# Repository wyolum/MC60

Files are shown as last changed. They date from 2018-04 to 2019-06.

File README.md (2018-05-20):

# MC60
break out board for Quectel MC60 Ultra-small LCC Quad-band GSM/GPRS/GNSS Module

http://www.quectel.com/product/mc60.htm

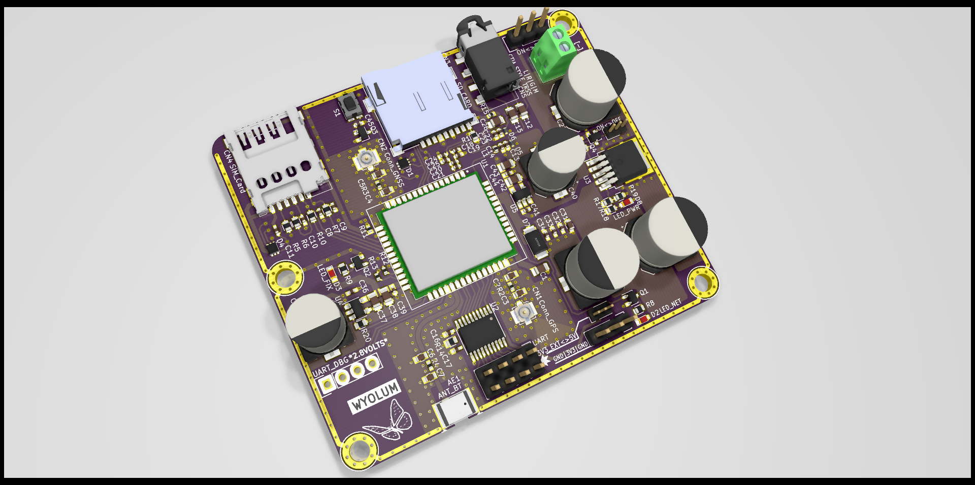
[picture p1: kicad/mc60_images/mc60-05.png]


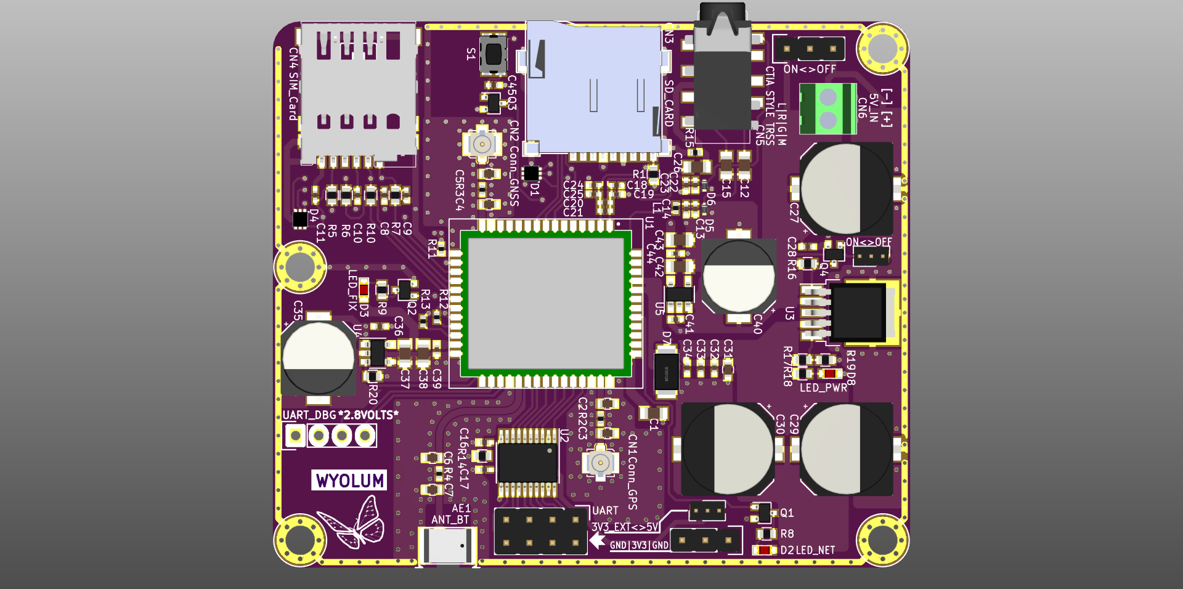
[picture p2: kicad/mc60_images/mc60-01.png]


License
-------
[CERN Open Hardware Licence v1.2 ]

[CERN Open Hardware Licence v1.2 ]:http://www.ohwr.org/attachments/2388/cern_ohl_v_1_2.txt

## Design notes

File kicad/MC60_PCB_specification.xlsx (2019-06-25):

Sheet: Template
PCB Name 名称 | MC60
Board Size 尺寸 | Length*width (Unit:mm) | 70 | * | 60
Material 板材 | (Rigid) FR－4 | Special Requirement:
Layers 层数 | 2 | Special Requirement:
Thickness 厚度 | 1.6 mm | Special Requirement:
Copper Weight 铜厚 | 1 oz. | Special Requirement:
Soldermask Color 阻焊颜色 | White | Special Requirement:
Silkscreen Color 丝印颜色 | Black | Special Requirement:
Surface Finishing 焊盘喷镀 | HASL Lead Free | Special Requirement:
Via soldermask 阻焊覆盖 | Soldermask Cover | Special Requirement:
Mini trace/spacing 最小线宽 | 0.20 mm | Special Requirement:
Mini hole size 最小孔径 | 0.40 mm | Special Requirement:
Special requirements 特殊工艺
 | Other Special requirements：

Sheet: Parameter
PCB Material | Layers | Thickness | Copper Weight | Soldermask Color | Silkscreen Color | Surface Finishing | Via soldermask | Mini trace/spacing | Mini hole size
FR-4 | 1 Layer | 0.6mm | 0.5 oz | Green | White | HASL Lead Free(RoHS) | Soldermask Cover | 4 mil or 0.10 mm | 6 mil or 0.15 mm
Flexible Printed Circuit | 2 Layer | 0.8mm | 1 oz | Red | Black | ENIG | Soldermask Opening | 5 mil or0.13 mm | 8 mil or 0.2 mm
Rogers 4003 | 4 Layer | 1.0mm | 2 oz | Blue | Yellow | OSP |  | 6 mil or 0.15 mm | 10 mil or 0.25 mm
Rogers 4350 | 6 Layer | 1.2mm | 3 oz | Black | Red | Immersion Tin |  | 8 mil or 0.20 mm | 12 mil or 0.30 mm
Taconic Series | 8 Layer | 1.3mm | Other | White | Other | Immersion Sliver
Aluminum-based material | 10 Layer | 1.6mm |  | Green Matte |  | Hard Gold
RF-35 | 12 Layer | 2.0mm |  | Blue Matte |  | Other
Arlon | 14 Layer | 2.5mm |  | Black Matte
Other | 16 Layer | 3.0mm |  | Other
 | Other | Other

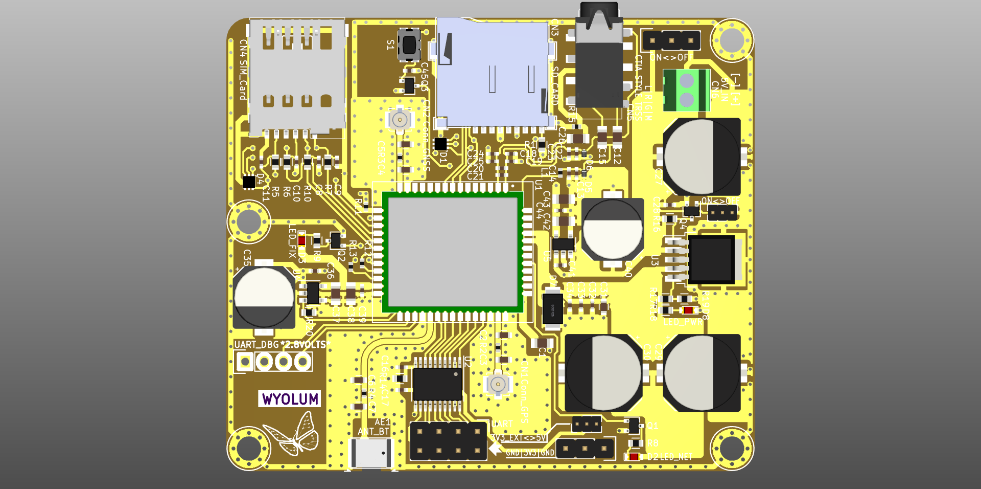
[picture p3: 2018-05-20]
kicad/mc60_images/mc60-03.png

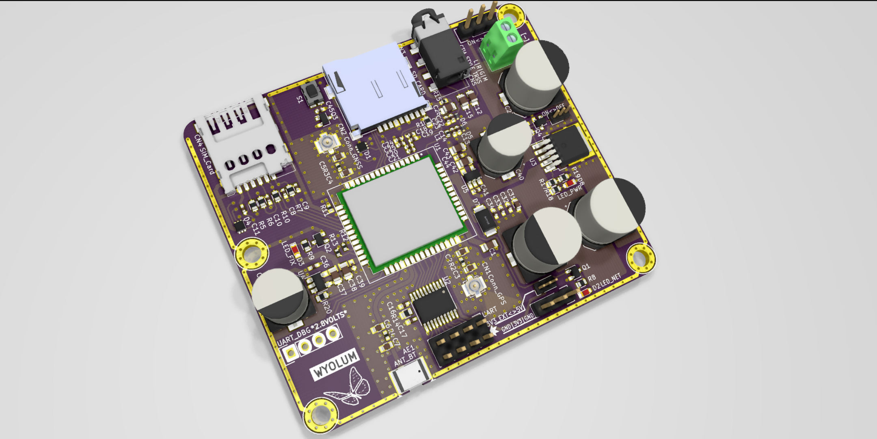
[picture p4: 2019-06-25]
kicad/mc60_images/mc60-05_2160x1080.png

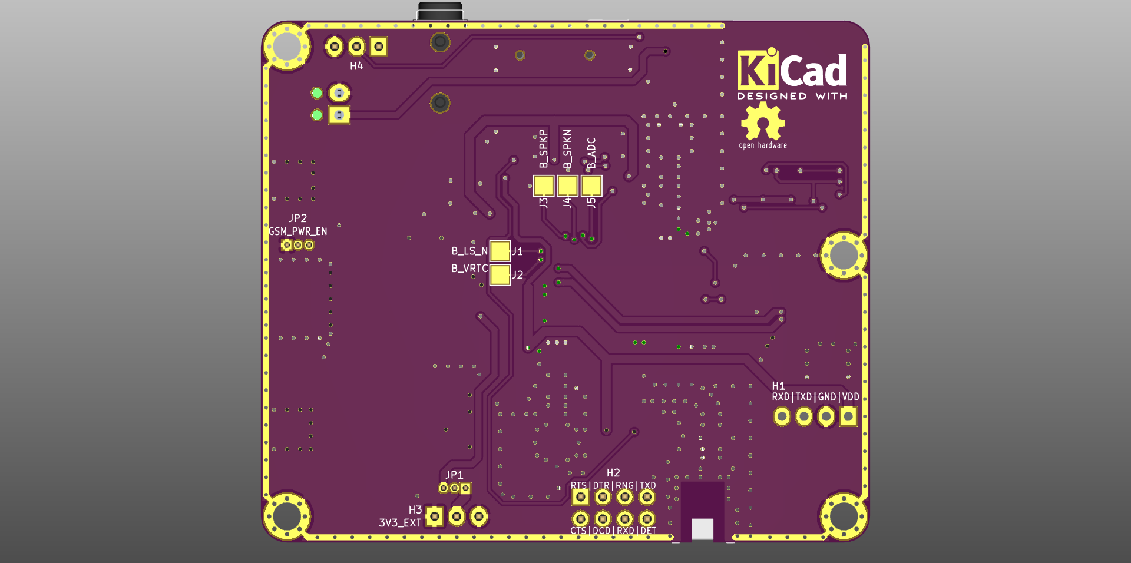
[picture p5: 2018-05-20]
kicad/mc60_images/mc60-02.png

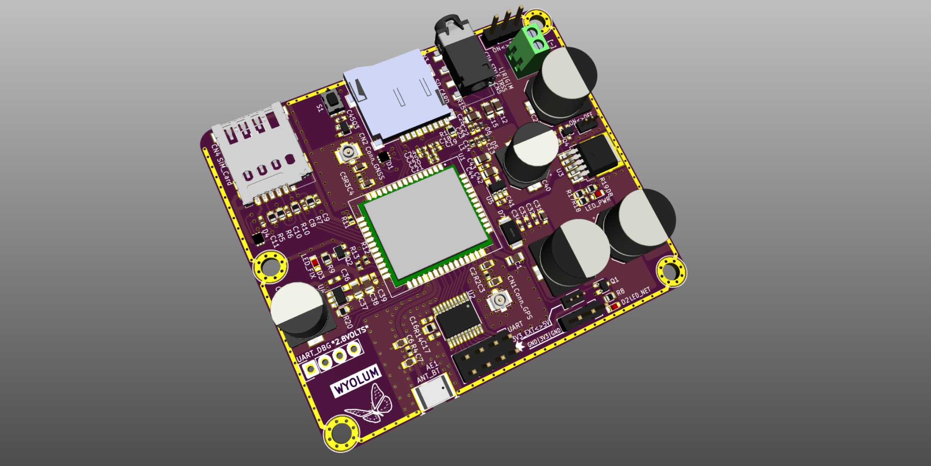
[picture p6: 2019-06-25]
kicad/mc60_images/mc60-06_2160x1080.png

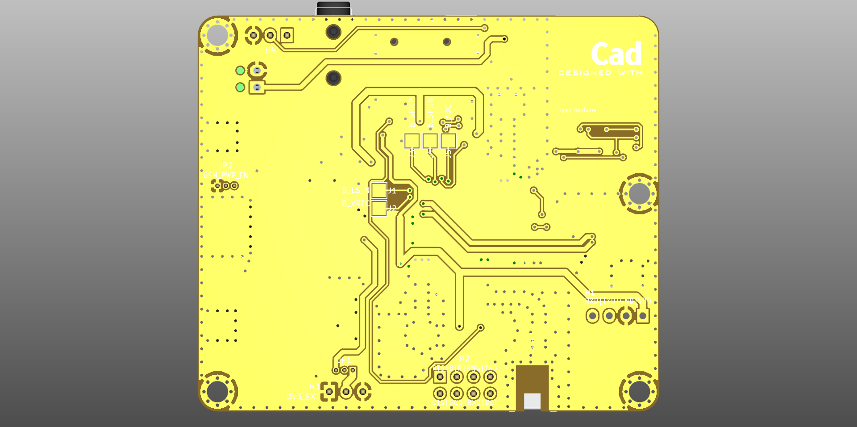
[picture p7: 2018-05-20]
kicad/mc60_images/mc60-04.png

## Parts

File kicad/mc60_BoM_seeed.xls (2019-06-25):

Electronic Engineering BOM List
Product Name：mc60
Version：V1
Issue Date：22/Jun/2019
Item No. (序号) | Reference Des (上件位置) | Qty (用量) | Catalog (分类） | Part_Description (规格描述) | Part_Value （元件值） | Part_Package （元件封装） | Manufacturers Name (使用厂牌名称) | Manufacturers Part No. (使用厂牌型号) | Distributors Name （供应商名称） | Distributors Part No. (供貨商型号) | Notes/Remark （备注）
Example（填写范例）
1 | AE1, | 1 | OTHER | SMD Built-in Antenna 2.4GHz;3P-5.2*3.7*0.7mm | ANT_BT | M5036 | Inpac | Inpac ACA-5036-A2-CC-S | Seeed | 318010123 | https://statics3.seeedstudio.com/images/opl/datasheet/318010123.pdf
2 | C1, C37, C42, | 3 | Capacitor | 0805 4.7uF ±10% 25V X7R | 4u7 | 0805 | TDK Corp | C2012X7R1E475KT000N | Shenzen OPL | -- | https://www.digikey.com/short/phhc0b
3 | C12, C15, C26, C38, C43, | 5 | Capacitor | 0805 10uF ±10% 16V X7R | 10uF | 0805 | Samsung | CL21B106KOQNNNE | Shenzen OPL | -- | https://www.digikey.com/short/phhc0c
4 | C14, C19, C21, C25, C23, C34, | 6 | Capacitor | 0402 10pF ±5% 50V C0G(NP0) | 10pF | 0402 | Samsung | CL05C100JB5NNNC | Shenzen OPL | -- | https://www.digikey.com/short/phhcdf
5 | C16, C17, C28, C32, C36, C39, C41, C44, | 8 | Capacitor | 0402 100nF ±10% 16V X7R | 100nF | 0402 | Murata | GRM155R71C104KA88D | Shenzen OPL | -- | https://www.digikey.com/short/phhcv1
6 | C27, C29, C30, | 3 | Capacitor | D10x10.5mm 470uF ±20% 25V 2000小时 -55°C~105°C | 470uF | Radial, Can – SMD, 10 mm dia | CapXon | HV471M025G105ETR | Shenzen OPL | -- | http://file.elecfans.com/web1/M00/69/6A/pIYBAFvX926AaMCkAAMMKAeSOCA257.pdf
7 | C31, | 1 | Capacitor | 0603 1uF ±10% 25V X7R | 1uF | 0603 | Samsung | CL10B105KA8NNNC | Shenzen OPL | -- | https://www.digikey.com/short/phh7tv
8 | C35, C40, | 2 | Capacitor | D8x10.5mm 100uF ±20% 50V 2000小时 -55°C~105°C | 100uF | Radial, Can – SMD, 8 mm dia | CapXon | HV101M050F105ETR | Shenzen OPL | -- | http://file.elecfans.com/web1/M00/69/6A/pIYBAFvX926AaMCkAAMMKAeSOCA257.pdf
9 | C8, C9, C10, C11, C13, C18, C20, C22, C24, C33, C45 | 11 | Capacitor | 0402 33pF ±5% 50V C0G(NP0) | 33pF | 0402 | Murata | GRM1555C1H330JA01D | Shenzen OPL | -- | https://www.digikey.com/short/phh7hz
10 | CN1, | 1 | Connector | U.FL (UMCC) Connector Receptacle, Male Pin 50Ohm Surface Mount Solder | Conn_GPS | SMD SMA U.FL (UMCC) | Hirose | U.FL-R-SMT-1 (80) | Shenzen OPL | -- | http://file.elecfans.com/web1/M00/90/FC/o4YBAFzPpouAOPsMAAeiikXVLw4340.pdf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
11 | CN2, | 1 | Connector | U.FL (UMCC) Connector Receptacle, Male Pin 50Ohm Surface Mount Solder | Conn_GNSS | SMD SMA U.FL (UMCC) | Hirose | U.FL-R-SMT-1 (80) | Shenzen OPL | -- | http://file.elecfans.com/web1/M00/90/FC/o4YBAFzPpouAOPsMAAeiikXVLw4340.pdf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
12 | CN3, | 1 | Connector | SMD Micro SD Card Socket | SD_CARD | SMD Micro SD | Sungtech | ST-TF-003A | Seeed | 320090000 | https://statics3.seeedstudio.com/images/opl/datasheet/320090000.pdf
13 | CN4, | 1 | Connector | SMD SIM Holder;15.45*12.65*1.45mm | SIM_Card | SMD SIM | Sungtech | ST-SIM-006M | Seeed | 320100004 | https://statics3.seeedstudio.com/images/opl/datasheet/320100004.pdf
14 | CN5, | 1 | Connector | SMD Audio Jack ; 3.5mm ; 4 Degree | Audio-Jack-4 | SMD | Sungtech | ST-PJ-930A | Seeed | 320040003 | https://statics3.seeedstudio.com/images/opl/datasheet/320040003.pdf
15 | CN6, | 1 | Connector | 2 Position Wire to Board Terminal Block Horizontal with Board 0.100" (2.54mm) Through Hole | 5V_IN | Through Hole Screw Terminal | Phoenix | 1725656 | Shenzen OPL | -- | https://www.digikey.com/short/phm703
16 | D1, D4, | 2 | Diode | TVS DIODE 5.5V 30V SLP1616P6 | RClamp0854P.TCT | 6-UFDFN Exposed Pad | Semtech Corporation | RCLAMP0854P.TCT | Digikey | RCLAMP0854P.TCTCT-ND | https://www.digikey.com/short/jznvrr
17 | D2, | 1 | Diode | Orange 605nm LED Indication - Discrete 2V 0603 (1608 Metric) | LED_NET | 0603 | Lite-On | LTST-C193KFKT-5A | Shenzen OPL | -- | https://www.digikey.com/short/phh709
18 | D3, | 1 | Diode | Orange 605nm LED Indication - Discrete 2V 0603 (1608 Metric) | LED_FIX | 0603 | Lite-On | LTST-C193KFKT-5A | Shenzen OPL | -- | https://www.digikey.com/short/phh709
19 | D5, D6, | 2 | Diode | TVS DIODE 5V SOD923 | ESD9B5.0ST5G | SOD923 | ON Semiconductor | ESD9B5.0ST5G | Shenzen OPL | -- | https://www.digikey.com/short/jzn4v3
20 | D7, | 1 | Diode | Zener Diode 5.1V 1W ±5.88% Surface Mount PMDTM | 5V1/1W | SOD-128 | Rohm Semiconductor | PDZVTR5.1B | Digikey | PDZVTR5.1BCT-ND | https://www.digikey.com/short/jznv05
21 | D8, | 1 | Diode | Orange 605nm LED Indication - Discrete 2V 0603 (1608 Metric) | LED_PWR | 0603 | Lite-On | LTST-C193KFKT-5A | Shenzen OPL | -- | https://www.digikey.com/short/phh709
22 | L1, | 1 | OTHER | Power Line Ferrite Bead 0402 (1005 Metric) 900mA 270mOhm, NOISE SUPPRESSION FILTER FOR AUDIO | 0E Bead | 0805 | TDK Corp | MAF1005GAD571DT000 | Digikey | 445-180342-1-ND | https://www.digikey.com/short/phm758
23 | Q1, Q2, Q3 | 3 | Transistor | Pre-Biased Bipolar Transistor (BJT) NPN - Pre-Biased 50V 100mA 250MHz 200mW Surface Mount SOT-323 | DTC114E | SC-70, SOT-323 | Diodes Inc. | DDTC114EUA-7-F | Digikey | DDTC114EUA-FDICT-ND | https://www.digikey.com/short/ph41pf
24 | Q4 | 1 | Transistor | Pre-Biased Bipolar Transistor (BJT) NPN - Pre-Biased 50V 100mA 250MHz 200mW Surface Mount SOT-323 | DTC143ZUA | SC-70, SOT-323 | Diodes Inc. | DDTC143ZUA-7-F | Digikey | DDTC143ZUA-FDICT-ND | https://www.digikey.com/short/ph414t
25 | R1, R5, | 2 | Resister | RES SMD 100K OHM 1% 1/10W 0603 | 100k | 0603 | Yageo | RC0603FR-07100KL | Shenzen OPL | -- | https://www.digikey.com/short/jzd7h3
26 | R14, | 1 | Resister | RES SMD 10K OHM 1% 1/10W 0603 | 10k | 0603 | RoyalOhm | 0603SAF1002T5E | Shenzen OPL | -- | https://www.digikey.com/short/jzd770
27 | R16, | 1 | Resister | RES SMD 51K OHM 1% 1/10W 0603 | 51k | 0603 | Yageo | RC0603FR-0751KL | Shenzen OPL | -- | https://www.digikey.com/short/jzd7jp
28 | R17, | 1 | Resister | RES SMD 124K OHM 1% 1/10W 0603 | 124k | 0603 | Yageo | RC0603FR-07124KL | Shenzen OPL | -- | https://www.digikey.com/short/jzd7b3
29 | R19, | 1 | Resister | RES SMD 56K OHM 1% 1/10W 0603 | 56k | 0603 | Yageo | RC0603FR-0756KL | Shenzen OPL | -- | https://www.digikey.com/short/jzd7zn
30 | R2, R3, R4, R11, R12, R13, R15, | 7 | Resister | RES SMD 0 OHM JUMPER 1/10W 0603 | 0E | 0603 | Yageo | RC0603FR-070RL | Shenzen OPL | -- | https://www.digikey.com/short/jzdc2c
31 | R20, | 1 | Resister | RES SMD 47K OHM 1% 1/10W 0603 | 47k | 0603 | Yageo | RC0603FR-0747KL | Shenzen OPL | -- | https://www.digikey.com/short/jzd7qb
32 | R6, R7, R10, | 3 | Resister | RES SMD 22 OHM 1% 1/10W 0603 | 22E | 0603 | Yageo | RC0603FR-0722RL | Shenzen OPL | -- | https://www.digikey.com/short/jzdc0h
33 | R8, R18, | 2 | Resister | RES SMD 390 OHM 1% 1/10W 0603 | 390E | 0603 | Yageo | RC0603FR-07390RL | Shenzen OPL | -- | https://www.digikey.com/short/jzdcvf
34 | R9, | 1 | Resister | RES SMD 270 OHM 1% 1/10W 0603 | 270E | 0603 | Yageo | RC0603FR-07270RL | Shenzen OPL | -- | https://www.digikey.com/short/jzd7c7
35 | S1, | 1 | OTHER | Tactile Switch SPST-NO Top Actuated Surface Mount | SW-ON | SMD Gull Wing 4.20mm x 3.20mm | Alps | SKRPADE010 | Shenzen OPL | -- | https://www.alps.com/prod/info/E/HTML/Tact/SurfaceMount/SKRP/SKRPADE010.html
36 | U1, | 1 | IC | GSM/GPRS/GNSS MC60 | MC60_0 | MC60 | Quectel | MC60 | Quectel | -- | http://www.quectel.com/product/mc60.htm
37 | U2, | 1 | IC | IC 8-BIT TRNSTR 15KV ESD 20TSSOP | TXB0108PWR | 20TSSOP | Texas Instruments | TXB0108PWR | Digikey | 296-21527-1-ND | https://www.digikey.com/short/jzdcp1
38 | U3, | 1 | IC | Linear Voltage Regulator IC 1 Output 3A TO-252-5 | MIC29302 | TO252-5 | Microchip Technology | MIC29302AWD-TR | Digikey | 576-4106-1-ND | https://www.digikey.com/short/jzdcj4
39 | U4, | 1 | IC | Linear Voltage Regulator IC Positive Fixed 1 Output 250mA SOT-23-5 | LP5907-3V3 | SOT23-5 | Texas Instruments | LP5907MFX-3.3/NOPB | Digikey | 296-38557-1-ND | https://www.digikey.com/short/ph41rp
40 | U5, | 1 | IC | Linear Voltage Regulator IC Positive Fixed 1 Output 250mA SOT-23-5 | LP5907-2V8 | SOT23-5 | Texas Instruments | LP5907MFX-2.8/NOPB | Digikey | 296-39063-1-ND | https://www.digikey.com/short/ph41rw
DO NOT POPULATE (But add parts separately in Kit of parts)
1 | C2, C3, C4, C5, C6, C7, | 6 | Capacitor | 0402 10pF ±5% 50V C0G(NP0) | 10pF_DNP | 0402 | Samsung | CL05C100JB5NNNC | Shenzen OPL | -- | https://www.digikey.com/short/phh3p0
2 | H1, | 1 | Connector | Header, Male, 2.54mm, 1 row x 4 way | UART_DBG |  | CJT | A2541WV-4P | Shenzen OPL | -- | https://www.digikey.com/short/phmc4z
3 | H2, | 1 | Connector | Header, Male, 2.54mm, 2 row x 4 way | UART |  | CJT | A2541WR-2x4P | Shenzen OPL | -- | https://www.digikey.com/short/phmczm
4 | H3, | 1 | Connector | Header, Male, 2.54mm, 1 row x 3 way | CONTROL |  | CJT | A2541WV-3P | Shenzen OPL | -- | https://www.digikey.com/short/phmcz0
5 | H4, | 1 | Connector | Header, Male, 2.54mm, 1 row x 3 way | ON<>OFF |  | CJT | A2541WV-3P | Shenzen OPL | -- | https://www.digikey.com/short/phmcz0
6 | JP1, | 1 | Connector | Header, Male, 1.27mm, 1 row x 3 way | 3V3_EXT<>5V |  | XPB | 210-1S-1*12P | Shenzen OPL | -- | https://www.digikey.com/short/phmcm1
7 | JP2, | 1 | Connector | Header, Male, 1.27mm, 1 row x 3 way | GSM_PWR_EN |  | XPB | 210-1S-1*12P | Shenzen OPL | -- | https://www.digikey.com/short/phmcm1
8 | -- | 1 | Connector | 2 (1 x 2) Position Shunt Connector Black Open Top 0.100" (2.54mm) Gold | -- | -- | Topt | JM1-1100-SBB-N0 | Shenzen OPL | -- | https://www.digikey.com/short/phhcqf
9 | -- | 2 | Connector | 2 (1 x 2) Position Shunt Connector Closed Top 0.050" (1.27mm) Gold | -- | -- | Sullins | NPB02SVAN-RC | Digikey | S9345-ND | https://www.digikey.com/short/phhc8h
1. Recommended Distributor: Digi-Key, Mouser, Avnet Express, Farnell.
2. Catalog: Capacitor,Resister,Diode,Connector,Transistor,IC,PROTECTOR CATEGORY,OTHER
3. Required Fields: Item No, Reference Des, Qty, Catalog, Part_Value, Part Package
Optional Fields: Part_Description, Manufacturers Name, Manufacturers Part No, Distributors Name, Distributors Part No, Unit Cost, Price break to use, Notes/Remark

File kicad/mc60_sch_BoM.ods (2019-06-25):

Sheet: mc60_sch
No | Reference | Value | Footprint
1 | AE1 | ANT_BT | mc60_fp:ant_bt_inpaq5036
2 | C1, C37, C42 | 4u7 | mc60_fp:C_0805
3 | C12, C15, C26, C38, C43 | 10uF | mc60_fp:C_0805
4 | C14, C19, C21, C23, C25, C34, | 10pF | mc60_fp:C_0402_NoSilk
5 | C16, C17, C28, C32, C36, C39, C41, C44, | 100nF | mc60_fp:C_0402_NoSilk
6 | C27, C29, C30 | 470uF | mc60_fp:CP_Elec_10x10
7 | C31 | 1uF | mc60_fp:C_0603
8 | C35, C40 | 100uF | mc60_fp:CP_Elec_8x10.5
9 | C8, C9, C10, C11, C13, C18, C20, C22, C24, C33, C45 | 33pF | mc60_fp:C_0402_NoSilk
10 | CN1 | Conn_GPS | mc60_fp:Molex_Microcoaxial_RF
11 | CN2 | Conn_GNSS | mc60_fp:Molex_Microcoaxial_RF
12 | CN3 | SD_CARD | mc60_fp:microsd-9-suntech-ST-TF-003A
13 | CN4 | SIM_Card | mc60_fp:conn_microSIM_320100004
14 | CN5 | Audio-Jack-4 | mc60_fp:AUDIO8P-SMD-3.5-14.5X6X5MM
15 | CN6 | 5V_IN | mc60_fp:conn_screw_2.54mm_2pol
16 | D1, D4 | RClamp0854P.TCT | mc60_fp:SLP1616P6
17 | D2 | LED_NET | mc60_fp:LED_0603
18 | D3 | LED_FIX | mc60_fp:LED_0603
19 | D5, D6 | ESD9B5.0ST5G | mc60_fp:D_SOD-923
20 | D7 | PDZVTR5.1B | mc60_fp:D_SOD-128
21 | D8 | LED_PWR | mc60_fp:LED_0603
22 | L1 | 0E | mc60_fp:R_0402_NoSilk
23 | Q1, Q2 Q3 | DTC114E | mc60_fp:SOT-323_SC-70
24 | Q4 | DTC143ZUA | mc60_fp:SOT-323_SC-70
25 | R1, R5 | 100k | mc60_fp:R_0603
26 | R14 | 10k | mc60_fp:R_0603
27 | R16 | 51k | mc60_fp:R_0603
28 | R17 | 124k | mc60_fp:R_0603
29 | R19 | 56k | mc60_fp:R_0603
30 | R2, R3, R4, R11, R12, R13, R15 | 0E | mc60_fp:R_0402_NoSilk
31 | R20 | 47k | mc60_fp:R_0603
32 | R6, R7, R10 | 22E | mc60_fp:R_0603
33 | R8, R18 | 390E | mc60_fp:R_0603
34 | R9 | 270E | mc60_fp:R_0603
35 | S1 | SW-ON | mc60_fp:SW_SPST_DTSM
36 | U1 | MC60_0 | mc60_fp:XCVR_MC60
37 | U2 | TXB0108PWR | mc60_fp:TSSOP-20_4.4x6.5mm_Pitch0.65mm
38 | U3 | MIC29302 | mc60_fp:TO-252-5_TabPin3
39 | U4 | LP5907-3V3 | mc60_fp:SOT-23-5
40 | U5 | LP5907-2V8 | mc60_fp:SOT-23-5
 | DNP PARTS
41 | C2, C3, C4, C5, C6, C7 | 10pF_DNP | mc60_fp:C_0603
42 | H1 | UART_DBG | mc60_fp:Pin_Header_Straight_1x04
43 | H2 | UART | mc60_fp:Pin_Header_Straight_2x04
44 | H3 | 3V3_EXT | mc60_fp:Pin_Header_Straight_1x03
45 | H4 | ON<>OFF | mc60_fp:Pin_Header_Straight_1x03
46 | JP1 | 3V3_EXT<>5V | mc60_fp:Pin_Header_Straight_1x03_Pitch1.27mm
47 | JP2 | GSM_PWR_EN | mc60_fp:Pin_Header_Straight_1x03_Pitch1.27mm
 | VIRTUAL PARTS
48 | G1 | OSHW | mc60_fp:Logo_silk_OSHW_6x6mm
49 | G2 | KiCad | mc60_fp:KiCad-Logo3_6mm_SilkScreen
50 | G3 | LOGO_WL | mc60_fp:logo_wyo3
51 | J1 | B_LS_N | mc60_fp:Test_Point_Pad_2.0x2.0mm
52 | J2 | B_VRTC | mc60_fp:Test_Point_Pad_2.0x2.0mm
53 | J3 | B_SPKP | mc60_fp:Test_Point_Pad_2.0x2.0mm
54 | J4 | B_SPKN | mc60_fp:Test_Point_Pad_2.0x2.0mm
55 | J5 | B_ADC | mc60_fp:Test_Point_Pad_2.0x2.0mm
56 | SC1, SC2, SC3, SC4 | SCREW | mc60_fp:mtg_hole_3mm_vias_2

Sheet: mc60_pcb
Id | Designator | Package | Quantity | Designation
1 | AE1 | ant_bt_inpaq5036 | 1 | ANT_BT
2 | C1, C37, C42 | C_0805 | 3 | 4u7
3 | C12, C15, C26, C38, C43 | C_0805 | 5 | 10uF
4 | C14, C19, C21, C23, C25, C34 | C_0402_NoSilk | 6 | 10pF
5 | C16, C17, C28, C32, C36, C39, C41, C44 | C_0402_NoSilk | 8 | 100nF
6 | C27, C29, C30 | CP_Elec_10x10 | 3 | 470uF
7 | C31 | C_0603 | 1 | 1uF
8 | C35, C40 | CP_Elec_8x10.5 | 2 | 100uF
9 | C8, C9, C10, C11, C13, C18, C20, C22, C24, C33, C45 | C_0402_NoSilk | 11 | 33pF
10 | CN1 | Molex_Microcoaxial_RF | 1 | Conn_GPS
11 | CN2 | Molex_Microcoaxial_RF | 1 | Conn_GNSS
12 | CN3 | microsd-9-suntech-ST-TF-003A | 1 | SD_CARD
13 | CN4 | conn_microSIM_320100004 | 1 | SIM_Card
14 | CN5 | AUDIO8P-SMD-3.5-14.5X6X5MM | 1 | Audio-Jack-4
15 | CN6 | conn_screw_2.54mm_2pol | 1 | 5V_IN
16 | D1, D4 | SLP1616P6 | 2 | RClamp0854P.TCT
17 | D2 | LED_0603 | 1 | LED_NET
18 | D3 | LED_0603 | 1 | LED_FIX
19 | D5, D6 | D_SOD-923 | 2 | ESD9B5.0ST5G
20 | D7 | D_SOD-128 | 1 | PDZVTR5.1B
21 | D8 | LED_0603 | 1 | LED_PWR
22 | L1 | R_0402_NoSilk | 1 | 0E
23 | Q1, Q2, Q3 | SOT-323_SC-70 | 3 | DTC114E
24 | Q4 | SOT-323_SC-70 | 1 | DTC143ZUA
25 | R1, R5 | R_0603 | 2 | 100k
26 | R14 | R_0603 | 1 | 10k
27 | R16 | R_0603 | 1 | 51k
28 | R17 | R_0603 | 1 | 124k
29 | R19 | R_0603 | 1 | 56k
30 | R2, R3, R4, R11, R12, R13, R15, | R_0402_NoSilk | 7 | 0E
31 | R20 | R_0603 | 1 | 47k
32 | R6, R7, R10 | R_0603 | 3 | 22E
33 | R8, R18 | R_0603 | 2 | 390E
34 | R9 | R_0603 | 1 | 270E
35 | S1 | SW_SPST_WS_TASV | 1 | SW-ON
36 | U1 | XCVR_MC60 | 1 | MC60_0
37 | U2 | TSSOP-20_4.4x6.5mm_Pitch0.65mm | 1 | TXB0108PWR
38 | U3 | TO-252-5_TabPin3 | 1 | MIC29302
39 | U4 | SOT-23-5 | 1 | LP5907-3V3
40 | U5 | SOT-23-5 | 1 | LP5907-2V8
 | DNP
41 | C2, C3, C4, C5, C6, C7 | C_0603 | 6 | 10pF_DNP
42 | H1 | Pin_Header_Straight_1x04 | 1 | UART_DBG
43 | H2 | Pin_Header_Straight_2x04 | 1 | UART
44 | H3 | Pin_Header_Straight_1x03 | 1 | 3V3_EXT
45 | H4 | Pin_Header_Straight_1x03 | 1 | ON<>OFF
46 | JP1 | Pin_Header_Straight_1x03_Pitch1.27mm | 1 | 3V3_EXT<>5V
47 | JP2 | Pin_Header_Straight_1x03_Pitch1.27mm | 1 | GSM_PWR_EN
 | VIRTUAL
48 | G1 | Logo_silk_OSHW_6x6mm_mask | 1 | OSHW
49 | G2 | KiCad-Logo3_6mm_SilkScreen | 1 | KiCad
50 | G3 | logo_wyo3 | 1 | LOGO_WL
51 | J1 | Test_Point_Pad_2.0x2.0mm | 1 | B_LS_N
52 | J2 | Test_Point_Pad_2.0x2.0mm | 1 | B_VRTC
53 | J3 | Test_Point_Pad_2.0x2.0mm | 1 | B_SPKP
54 | J4 | Test_Point_Pad_2.0x2.0mm | 1 | B_SPKN
55 | J5 | Test_Point_Pad_2.0x2.0mm | 1 | B_ADC
56 | SC1, SC2, SC3, SC4 | mtg_hole_3mm_vias_2 | 4 | SCREW

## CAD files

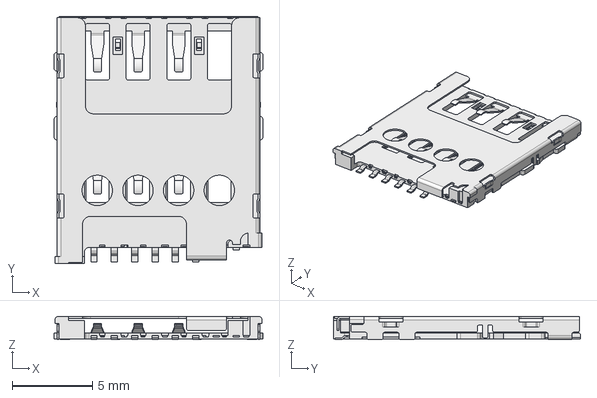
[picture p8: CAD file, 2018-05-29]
kicad/3d_modules/microSIM_3D.step
13.0 x 15.5 x 1.45 mm

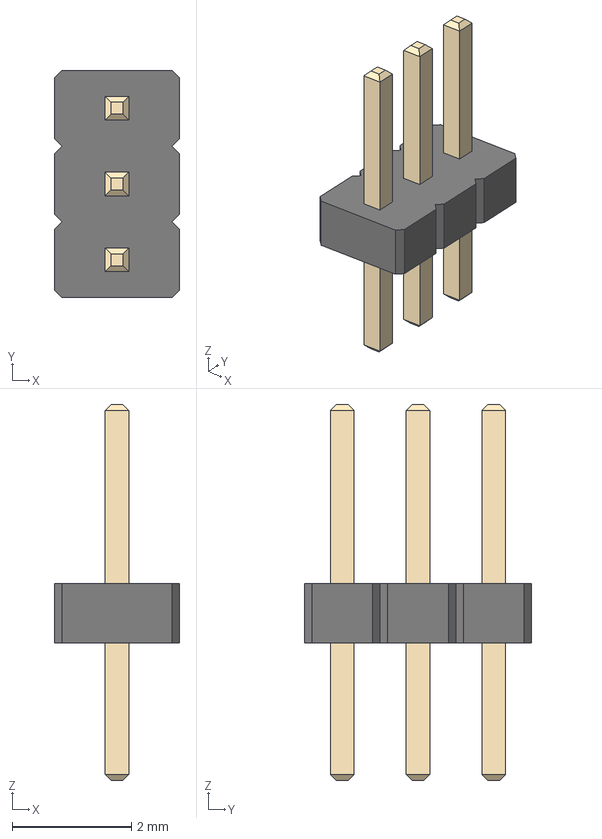
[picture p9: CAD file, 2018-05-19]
kicad/3d_modules/Pin_Header_Straight_1x03_Pitch127mm.step
2.10 x 3.81 x 6.30 mm

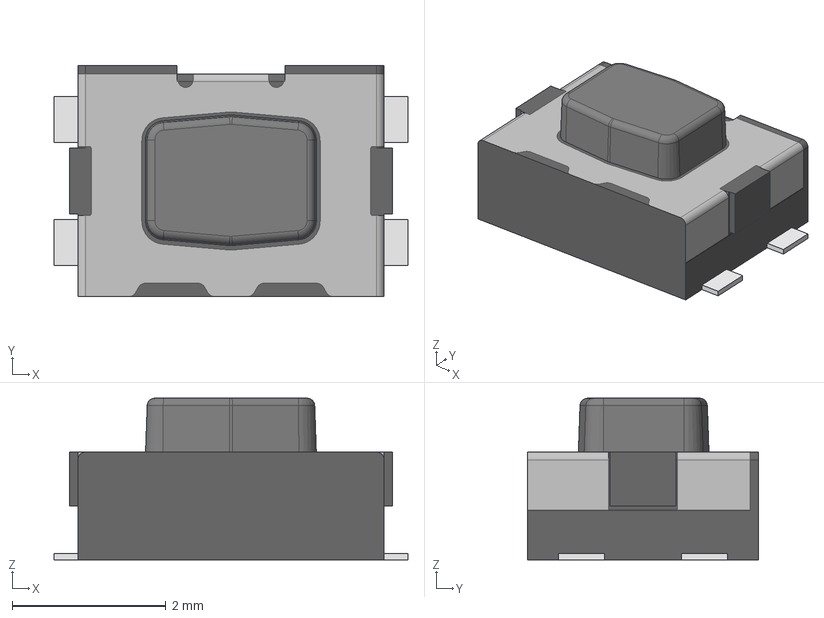
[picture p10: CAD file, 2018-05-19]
kicad/3d_modules/SW_SPST_WS_TASV.step
4.60 x 3.00 x 2.10 mm

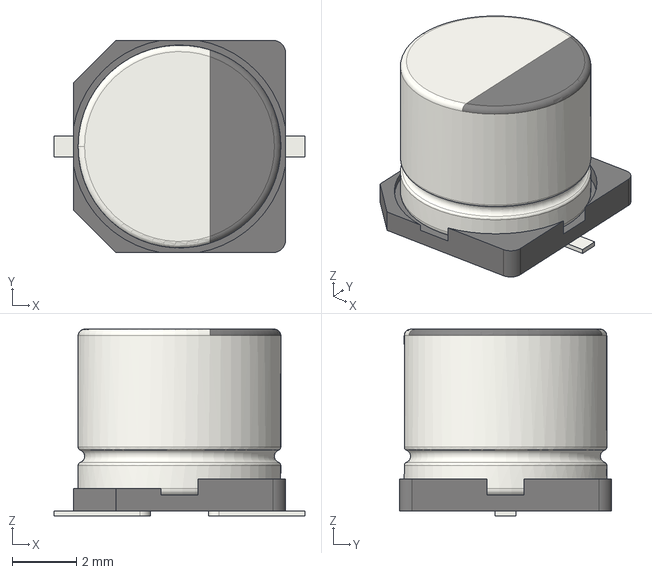
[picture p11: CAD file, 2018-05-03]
kicad/3d_modules/CP_Elec_6.3x5.8.step
7.80 x 6.60 x 5.80 mm

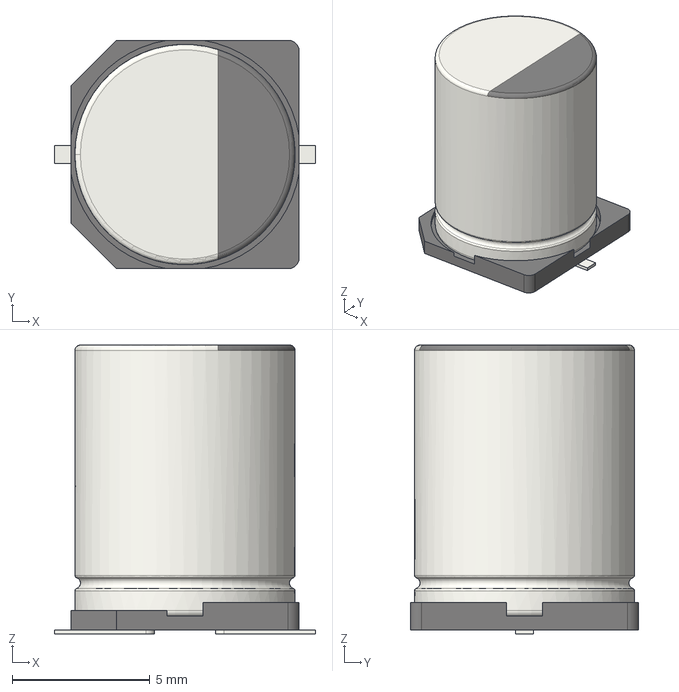
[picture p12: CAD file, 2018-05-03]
kicad/3d_modules/CP_Elec_8x10.5.step
9.50 x 8.30 x 10.5 mm

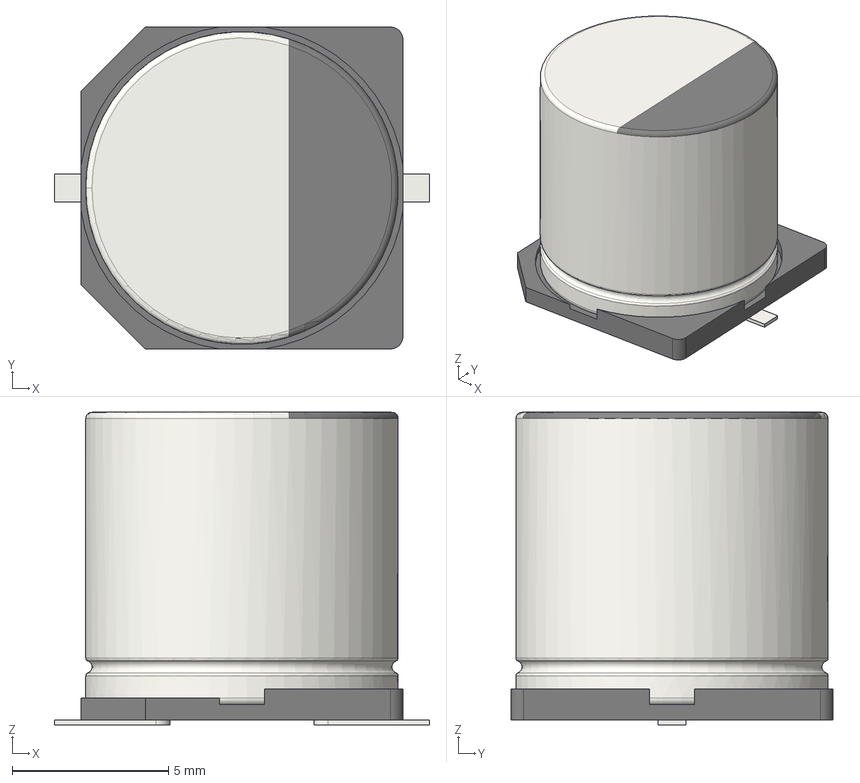
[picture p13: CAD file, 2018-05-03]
kicad/3d_modules/CP_Elec_10x10.step
12.0 x 10.3 x 10.0 mm

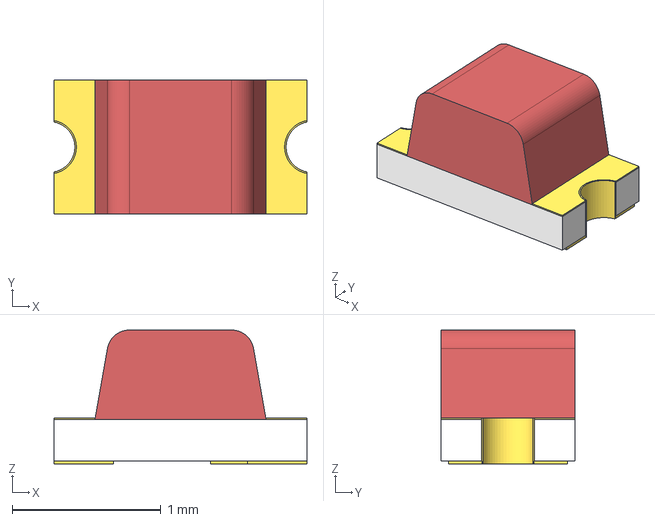
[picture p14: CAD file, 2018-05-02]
kicad/3d_modules/diode_LED_0603_LTST.step
1.70 x 0.9 x 0.9 mm

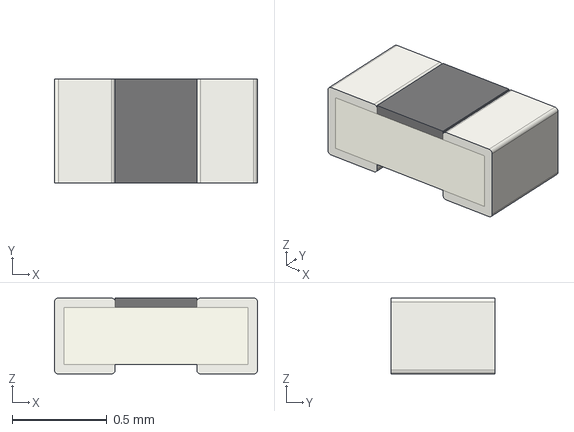
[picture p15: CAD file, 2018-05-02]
kicad/3d_modules/R_0402.step
1.07 x 0.55 x 0.4 mm

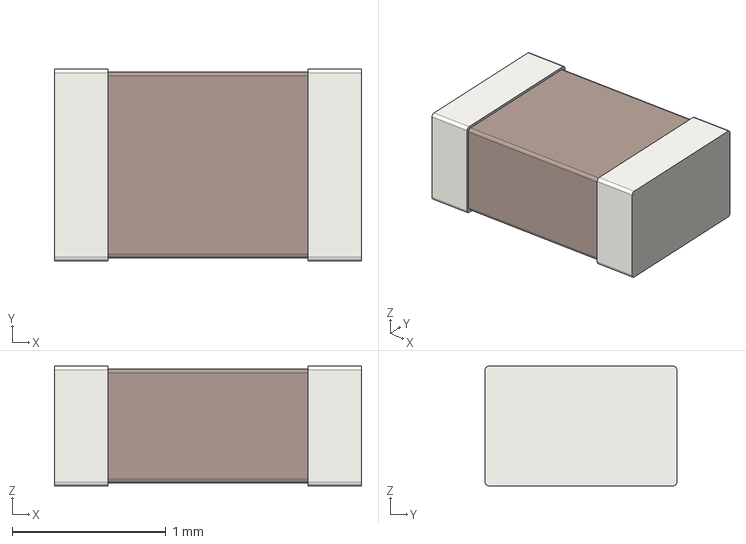
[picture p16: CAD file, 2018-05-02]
kicad/3d_modules/C_0805.step
2.00 x 1.25 x 0.78 mm

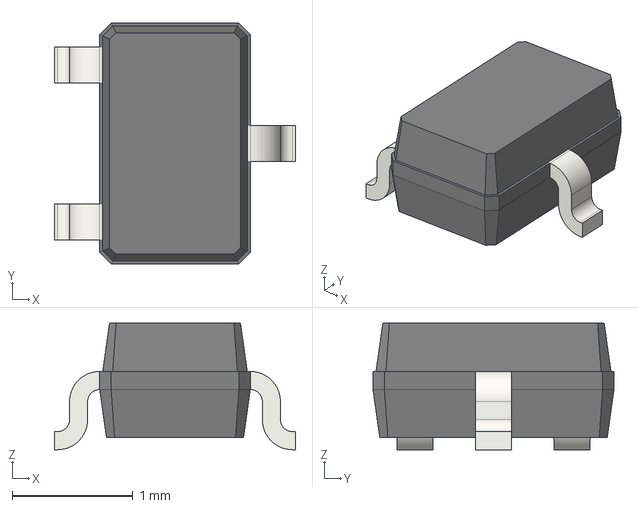
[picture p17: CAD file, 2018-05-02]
kicad/3d_modules/SOT_323_SC_70.step
2.00 x 2.00 x 1.05 mm

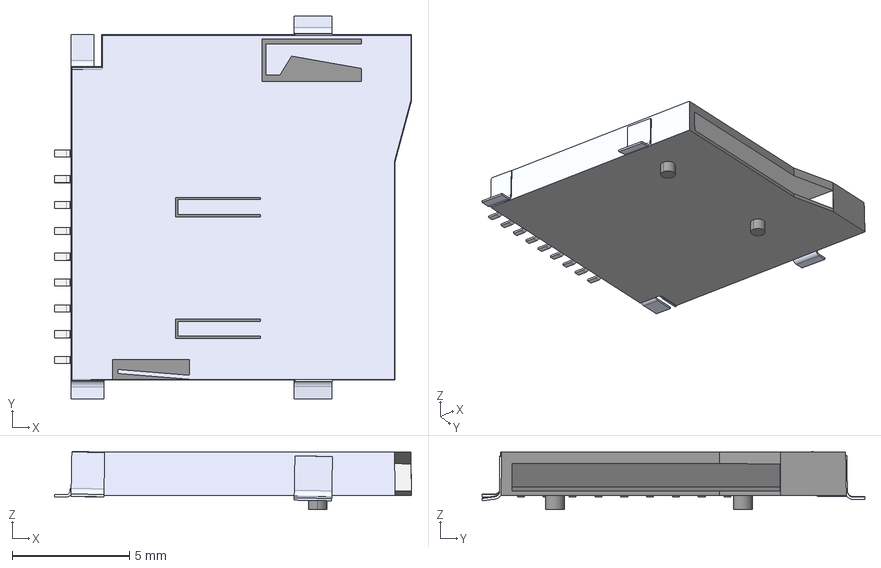
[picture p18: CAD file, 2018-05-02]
kicad/3d_modules/conn_micro_SD_02.step
15.2 x 16.3 x 2.47 mm

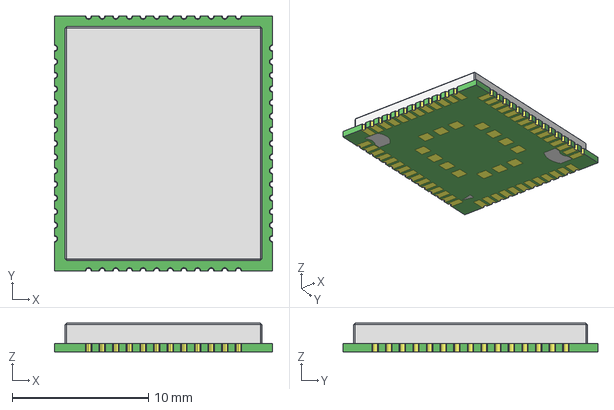
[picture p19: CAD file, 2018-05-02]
kicad/3d_modules/User_Library_Quectel_MC60_cp.step
16.0 x 18.7 x 2.10 mm

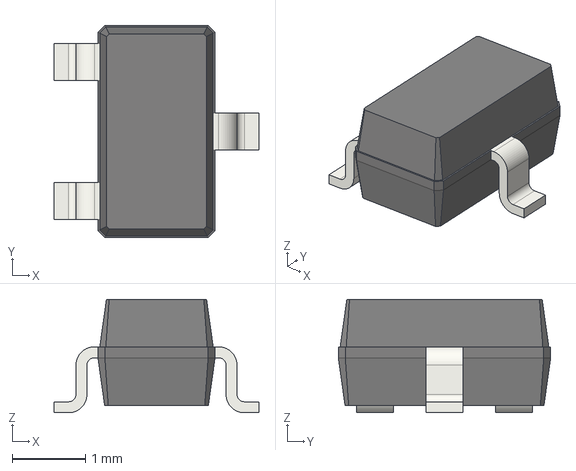
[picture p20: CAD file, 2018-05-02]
kicad/3d_modules/SOT_23.step
2.80 x 2.90 x 1.55 mm

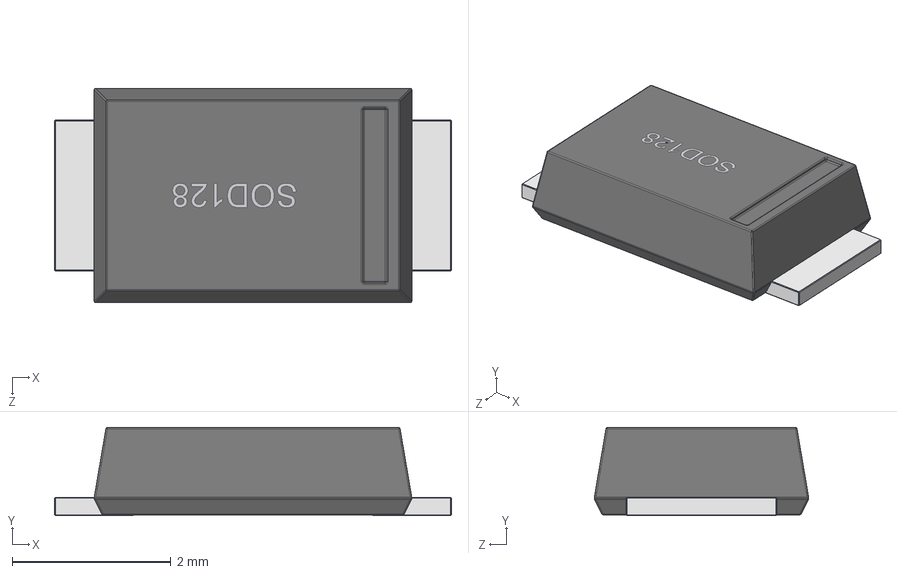
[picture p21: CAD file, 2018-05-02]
kicad/3d_modules/D-SOD128.step
5.00 x 1.11 x 2.70 mm

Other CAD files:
kicad/3d_modules/conn-Micro SD.step
kicad/3d_modules/R_0603.step
kicad/3d_modules/conn_rf_uFL_3450020P1.step
kicad/3d_modules/Pin_Header_Straight_2x04_Pitch254mm.step
kicad/3d_modules/732511150.step
kicad/3d_modules/786463001.stp
kicad/3d_modules/CUI_SJ-43514-SMT-TR.step
kicad/3d_modules/C_0402.step
kicad/3d_modules/C_0603.step
kicad/3d_modules/D-SOD923.step
kicad/3d_modules/Pin_Header_Straight_1x03_Pitch254mm.step
kicad/3d_modules/Quectel_MC60.step
kicad/3d_modules/SLP1616P6.step
kicad/3d_modules/SLP1616P6_3D.step
kicad/3d_modules/SOT_23_5.step
kicad/3d_modules/TO_252_5_TabPin3.step
kicad/3d_modules/TSSOP_20_44x65mm_Pitch065mm.step
kicad/3d_modules/U_FL-R-SMT(10).step
kicad/3d_modules/ant_bt_inpaq.fcstd
kicad/3d_modules/ant_bt_inpaq.step
kicad/3d_modules/ant_bt_inpaq_5036.step
kicad/3d_modules/conn_microSIM_320100004.step
kicad/3d_modules/conn_micro_SD_01.step
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

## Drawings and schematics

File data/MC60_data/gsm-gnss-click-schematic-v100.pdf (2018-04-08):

# GSM/GNSS click schematic v100

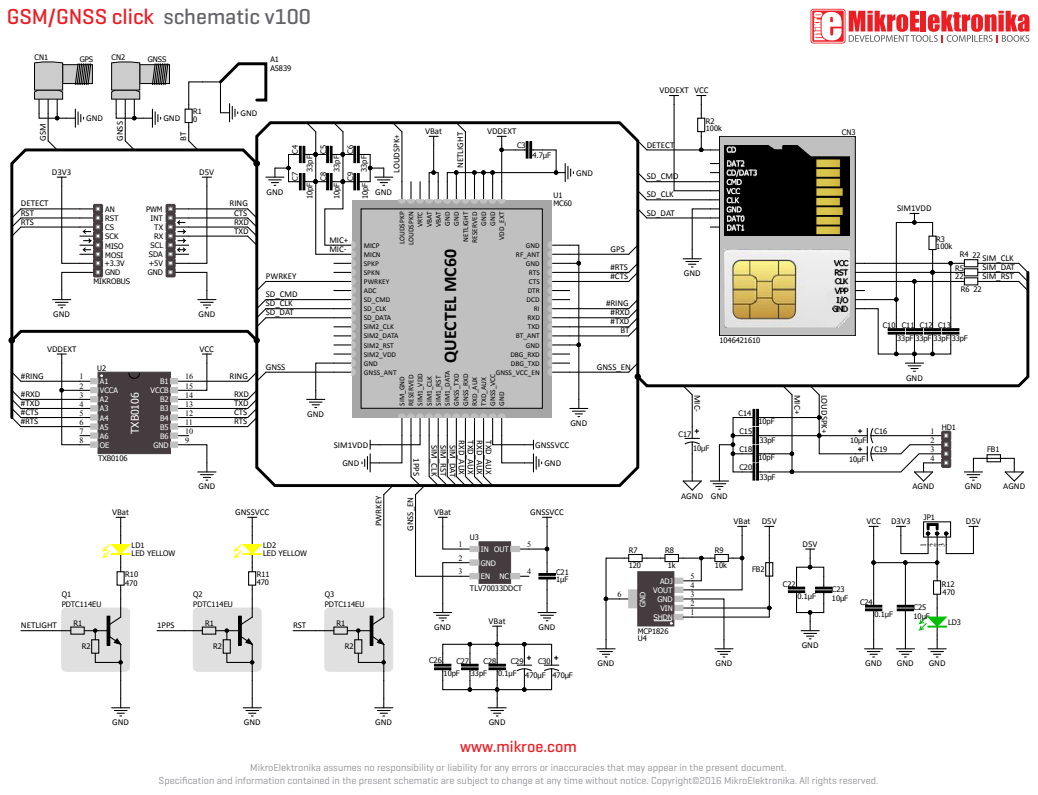
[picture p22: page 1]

MikroElektronika assumes no responsibility or liability for any errors or inaccuracies that may appear in the present document.

Specification and information contained in the present schematic are subject to change at any time without notice. Copyright©2016 MikroElektronika. All rights reserved.

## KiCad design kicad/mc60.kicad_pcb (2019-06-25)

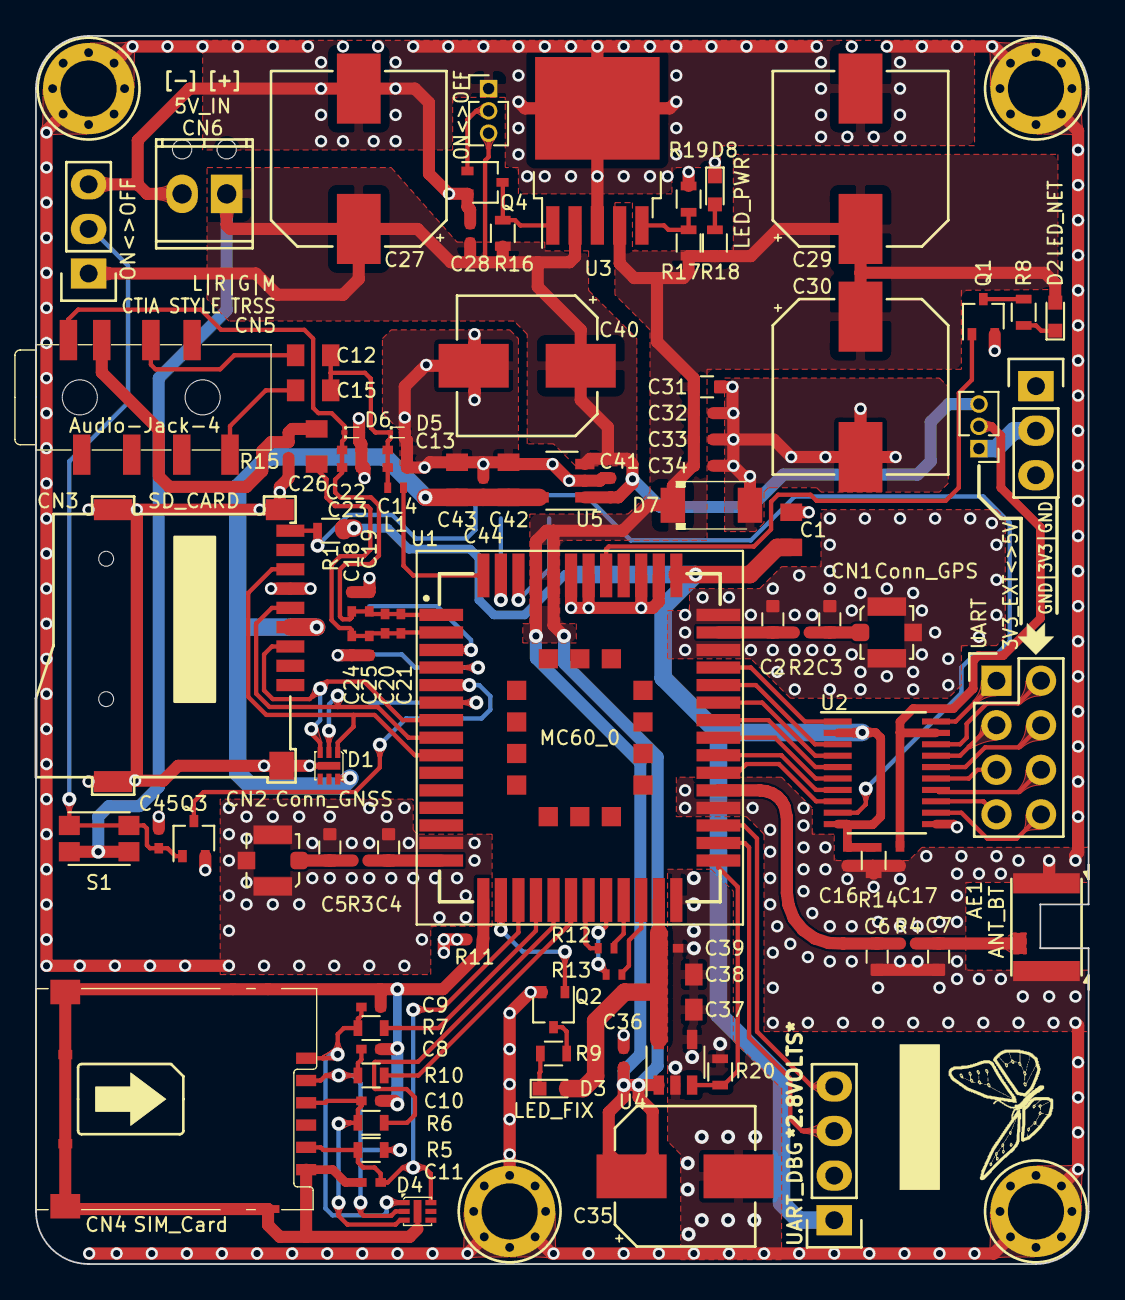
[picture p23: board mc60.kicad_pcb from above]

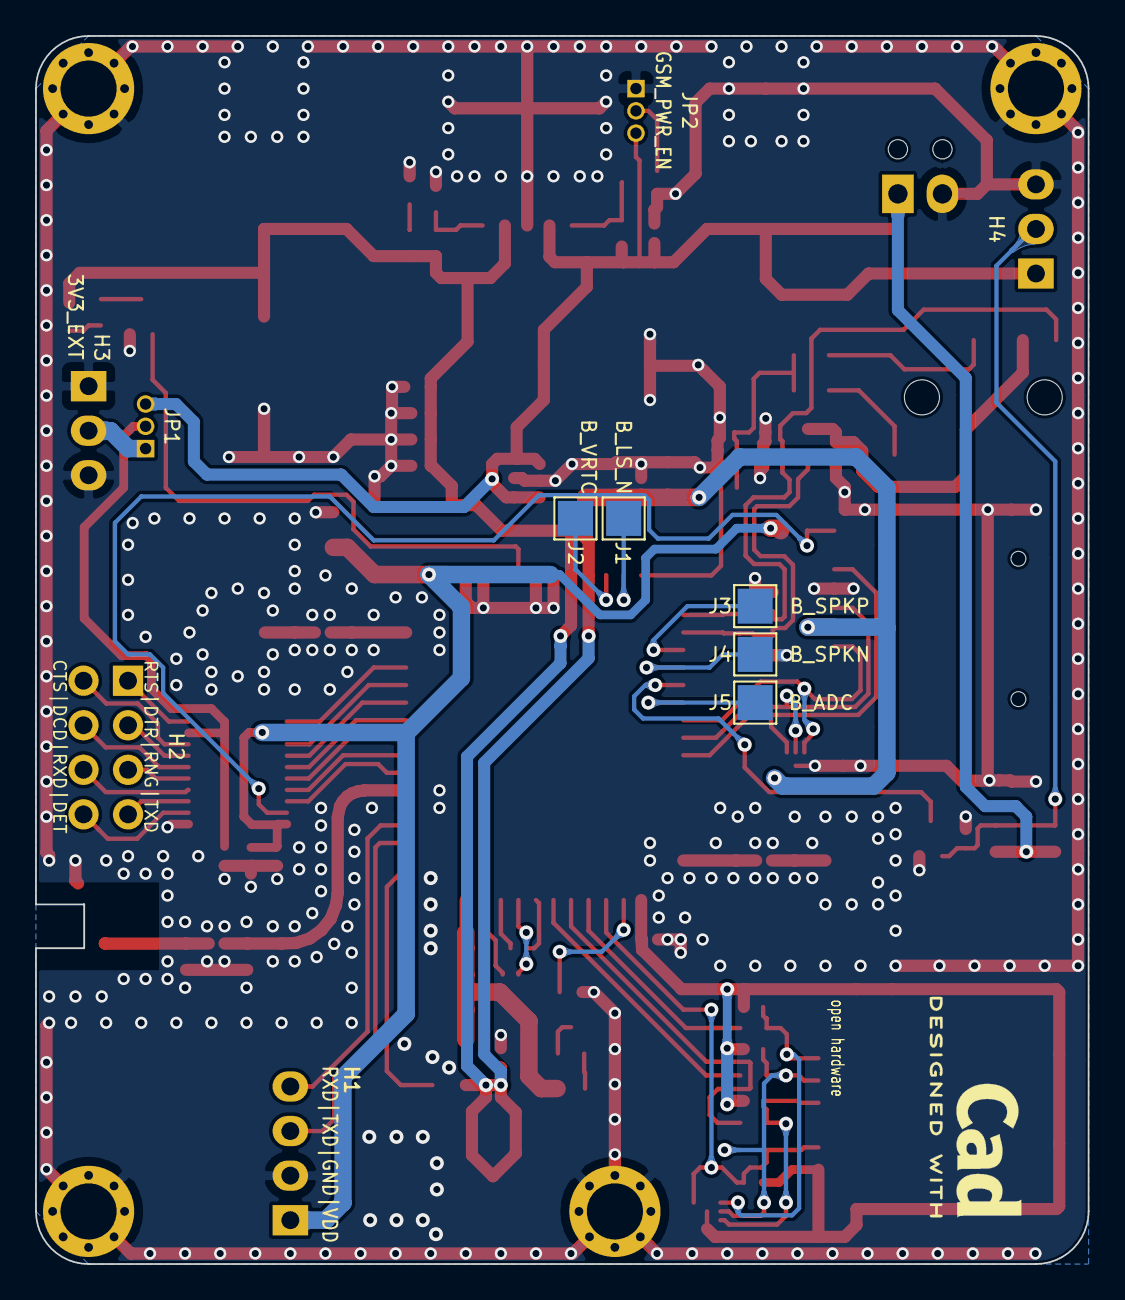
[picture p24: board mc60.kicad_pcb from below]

Board: 2 copper layers, 60.0 x 70.0 mm, 109 parts (7 on the bottom side), 72 nets.

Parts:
AE1: ANT_BT; ant_bt_inpaq5036
C1, C37, C42: 4u7; C_0805
C2, C3, C4, C5, C6, C7: 10pF_DNP; C_0603
C8, C9, C10, C11, C13, C18, C20, C22, C24, C33, C45: 33pF; C_0402_NoSilk
C12, C15, C26, C38, C43: 10uF; C_0805
C14, C19, C21, C23, C25, C34: 10pF; C_0402_NoSilk
C16, C17, C28, C32, C36, C39, C41, C44: 100nF; C_0402_NoSilk
C27, C29, C30: 470uF; CP_Elec_10x10
C31: 1uF; C_0603
C35, C40: 100uF; CP_Elec_8x10.5
CN1: Conn_GPS; Molex_Microcoaxial_RF
CN2: Conn_GNSS; Molex_Microcoaxial_RF
CN3: SD_CARD; microsd-9-suntech-ST-TF-003A
CN4: SIM_Card; conn_microSIM_320100004
CN5: Audio-Jack-4; AUDIO8P-SMD-3.5-14.5X6X5MM
CN6: 5V_IN; conn_screw_2.54mm_2pol
D1, D4: RClamp0854P.TCT; SLP1616P6
D2: LED_NET; LED_0603
D3: LED_FIX; LED_0603
D5, D6: ESD9B5.0ST5G; D_SOD-923
D7: PDZVTR5.1B; D_SOD-128
D8: LED_PWR; LED_0603
G1: OSHW; Logo_silk_OSHW_6x6mm_mask
G2: KiCad; KiCad-Logo3_6mm_SilkScreen
G3: LOGO_WL; logo_wyo3
H1: UART_DBG; Pin_Header_Straight_1x04
H2: UART; Pin_Header_Straight_2x04
H3: 3V3_EXT; Pin_Header_Straight_1x03
H4: ON<>OFF; Pin_Header_Straight_1x03
J1: B_LS_N; Test_Point_Pad_2.0x2.0mm
J2: B_VRTC; Test_Point_Pad_2.0x2.0mm
J3: B_SPKP; Test_Point_Pad_2.0x2.0mm
J4: B_SPKN; Test_Point_Pad_2.0x2.0mm
J5: B_ADC; Test_Point_Pad_2.0x2.0mm
JP1: 3V3_EXT<>5V; Pin_Header_Straight_1x03_Pitch1.27mm
JP2: GSM_PWR_EN; Pin_Header_Straight_1x03_Pitch1.27mm
L1: 0E; R_0402_NoSilk
Q1, Q2, Q3: DTC114E; SOT-323_SC-70
Q4: DTC143ZUA; SOT-323_SC-70
R1, R5: 100k; R_0603
R2, R3, R4, R11, R12, R13, R15: 0E; R_0402_NoSilk
R6, R7, R10: 22E; R_0603
R8, R18: 390E; R_0603
R9: 270E; R_0603
R14: 10k; R_0603
R16: 51k; R_0603
R17: 124k; R_0603
R19: 56k; R_0603
R20: 47k; R_0603
S1: SW-ON; SW_SPST_WS_TASV
SC1, SC2, SC3, SC4: SCREW; mtg_hole_3mm_vias_2
U1: MC60_0; XCVR_MC60
U2: TXB0108PWR; TSSOP-20_4.4x6.5mm_Pitch0.65mm
U3: MIC29302; TO-252-5_TabPin3
U4: LP5907-3V3; SOT-23-5
U5: LP5907-2V8; SOT-23-5

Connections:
/1PPS: Q2.1, U1.17
/2V8_SD: C42.1, C43.1, C44.1, CN3.4, D1.6, U5.5
/3V3_EXT: H3.2, JP1.1
/ADC: J5.1, U1.6
/ANT_BT: C6.2, R4.2, U1.32
/ANT_GNSS: C4.2, R3.2, U1.15
/ANT_GPS: C2.2, R2.2, U1.41
/CTS: H2.2, U2.18
/CTS>: U1.38, U2.3
/DBG_RXD: H1.4, U1.30
/DBG_TXD: H1.3, U1.29
/DCD: H2.4, U2.16
/DCD>: U1.36, U2.5
/DTR: H2.3, U2.17
/DTR>: U1.37, U2.4
/GNSSVCC: C37.1, C38.1, C39.1, D3.2, U1.26, U4.5
/GNSS_VCC_EN: R20.1, U1.28, U4.3
/GSM_PWR_EN: JP2.2, Q4.1
/LEFT: C15.2, CN5.4
/LOUD_SPKN: J1.1, U1.53
/LOUD_SPKP: L1.1, U1.54
/L_SP: C12.1, C13.2, C14.2, C15.1, D5.1, L1.2
/MIC_N: C20.1, C21.1, C24.2, C25.2, C26.1, U1.2
/MIC_P: C18.1, C19.1, C20.2, C21.2, C22.2, C23.2, CN5.1, D6.1, U1.1
/NETLIGHT: Q1.1, U1.47
/PWRKEY: Q3.3, U1.5
/RIGHT: C12.2, CN5.3
/RING: H2.5, U2.15
/RING>: U1.35, U2.6
/RST: C45.2, H4.2, Q3.1, S1.1
/RTS: H2.1, U2.20
/RTS>: U1.39, U2.1
/RXD: H2.6, U2.14
/RXD>: U1.34, U2.7
/RXD_AUX: R12.1, U1.24
/RXD_G: R13.2, U1.23
/SD_CLK: CN3.5, D1.2, U1.8
/SD_CMD: CN3.3, D1.3, U1.7
/SD_DAT: CN3.7, D1.1, U1.9
/SD_DET: H2.8, U2.12
/SD_DET>: CN3.9, R1.2, U2.9
/SIM1_VDD: C11.2, CN4.P1, D4.6, R5.1, U1.18
/SIMCLK: C9.2, CN4.P3, D4.1, R7.1
/SIMDAT: C8.2, CN4.P7, D4.2, R5.2, R10.1
/SIMRST: C10.2, CN4.P2, D4.3, R6.1
/SIM_CLK: R7.2, U1.19
/SIM_DAT: R10.2, U1.21
/SIM_RST: R6.2, U1.20
/SPKN: J4.1, U1.4
/SPKP: J3.1, U1.3
/TXD: H2.7, U2.13
/TXD>: U1.33, U2.8
/TXD_AUX: R13.1, U1.25
/TXD_G: R12.2, U1.22
/VCCB: C17.1, JP1.2, U2.19
/VDD_EXT: C1.1, C16.1, H1.1, R1.1, R14.1, U1.43, U2.2, U2.10
/VRTC: J2.1, U1.52
GND: AE1.1, C1.2, C2.1, C3.1, C4.1, C5.1, C6.1, C7.1, C13.1, C14.1, C16.2, C17.2, C18.2, C19.2, C22.1, C23.1, C24.1, C25.1, C27.2, C28.2, C29.2, C30.2, C31.2, C32.2, C33.2, C34.2, C35.2, C36.2, C37.2, C38.2, C39.2, C40.2, C41.2, C42.2, C43.2, C44.2, C45.1, CN1.2, CN2.2, CN3.6, CN3.G1, CN3.G2, CN3.G3, CN3.G4, CN6.2, D1.7, D5.2, D6.2, D7.2, D8.1, H1.2, H3.1, H3.3, H4.3, JP2.1, Q1.2, Q2.2, Q3.2, Q4.2, R11.2, R14.2, R15.2, R19.2, R20.2, SC1.1, SC2.1, SC3.1, SC4.1, U1.14, U1.27, U1.31, U1.40, U1.42, U1.44, U1.45, U1.48, U1.49, U2.11, U3.3, U4.2, U4.4, U5.2, U5.4
GNDD: C8.1, C9.1, C10.1, C11.1, CN4.G1, CN4.G2, CN4.G3, CN4.G4, CN4.G5, CN4.G6, CN4.G7, CN4.G8, CN4.P5, D4.7, R11.1, U1.16
GNDREF: C26.2, CN5.2, R15.1
unnamed: AE1.2, C7.2, R4.1
unnamed: C3.2, CN1.1, R2.1
unnamed: C5.2, CN2.1, R3.1
unnamed: D2.1, R8.1
unnamed: D3.1, R9.1
unnamed: D8.2, R18.2
unnamed: Q1.3, R8.2
unnamed: Q2.3, R9.2
unnamed: Q4.3, R16.2, U3.1
unnamed: R17.2, R19.1, U3.5
VBAT: C29.1, C30.1, C31.1, C32.1, C33.1, C34.1, C35.1, C36.1, D2.2, D7.1, R17.1, R18.1, U1.50, U1.51, U3.4, U4.1
VDD: C27.1, C28.1, C40.1, C41.1, CN6.1, H4.1, JP1.3, JP2.3, R16.1, S1.2, U3.2, U5.1, U5.3

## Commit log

2018-04-08 schematic wip
    [Quectel_MC60.step, mc60.kicad_pcb, mc60.sch]
2018-04-23 layout WIP
    [mc60.kicad_pcb, mc60.sch, mc60_sch_BoM.csv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]
2018-05-13 UART header update, added freeite bead on Loudspeaker, added Cap for Switch
    [mc60.kicad_pcb, mc60.sch]
2018-05-19 board layout WIP
    [Pin_Header_Straight_1x03_Pitch127mm.step, SW_SPST_WS_TASV.step, mc60.kicad_pcb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]
2018-05-19 board layout, WiP
    [mc60.kicad_pcb, mc60_pcb_BoM.csv]
2019-06-25 gerbers for first prototypes
    [732511150.step, 786463001.stp, CP_Elec_10x10.step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]
